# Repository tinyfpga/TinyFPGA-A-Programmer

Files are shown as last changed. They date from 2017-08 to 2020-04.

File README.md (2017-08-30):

# TinyFPGA Programmer
The TinyFPGA Programmer is a very simple USB-JTAG bridge designed to 
program bitstreams onto TinyFPGA A1 and A2 boards.  

## Serial Protocol
The programmer firmware appears as a generic USB serial port when you connect it
to a computer.  Control of the GPIO pins on the programmer is through this simple
serial interface.  

### Command Format
Commands are encoded as 8-bit bytes with a command type field and data payload.
The payload is typically a 6-bit bitmap representing the GPIO pins of the programmer.

| 7:6 | 5 | 4 | 3 | 2 | 1 | 0 |
|---|---|---|---|---|---|---|
| Command Type |TMS|TCK|TDI|TDO|RC1|RC0|

### Commands

|Opcode | Command |
|---|---|
| 0 | Configure Input/Output |
| 1 | Extended Command (Unused) |
| 2 | Set Outputs |
| 3 | Set Outputs and Sample Inputs |

#### Configure Input/Output
For each of the GPIO pins, set the direction of the pin.  
* 1: Set GPIO pin n to INPUT
* 0: Set GPIO pin n to OUTPUT

#### Extended Command
Reserved for future command expansion.

#### Set Outputs
Set each of the output pins to the given values.

#### Set Outputs and Sample Inputs
Set each of the output pins to the given values and return a byte representing
the current values of the input pins.  

### General Usage
For serial interfaces like JTAG this protocol divides the maximum possible bandwidth
by 8 from the USB to JTAG interface.  This means we might get 0.5MHz JTAG programming speed.
That speed is actually fast enough to transfer all the data to the FPGA in a few seconds.  However
the configuration flash on the FPGA actually needs a fair bit of time after erase and write operations
that will slow down the programming operatuon.

What can really slow down programming is the turnaround time for reading back data from the FPGA.  
For the most part data is going in one direction from the host computer to the programmer to the FPGA.  
For these cases we can  use the `Set Outputs` command and not wait for any data to return.  However 
there are times when we may  need to poll a status bit to see if the FPGA has finished an erase or 
write operation.  In this cases we will want to also sample the inputs and check the status.  These 
should not be timing sensitive because the FPGA is already busy.

Verifying the configuration data on the other hand could take a long time if not done carefully.  The
application talking to the programmer should make sure to write as many commands as it can before attempting
to read back the data from the serial interface.  Rather than paying a penalty for the turnaround time on
every read bit, we pay for it after reading dozens of bytes.  This should allow read-back of the configuration
data to be relatively quick and painless.

## Status
The project is currently in progress.  Initial schematic and PCBs have
been designed along with firmware for the USB microcontroller.  The PCBs
have been received from OSH Park and programmed with the firwmware.

The biggest task left is still developing the Python libraries for interfacing 
with the firmware and driving the JTAG interface and is currently in progress.

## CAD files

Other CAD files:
firmware/dist/default/production/firmware.production.obj

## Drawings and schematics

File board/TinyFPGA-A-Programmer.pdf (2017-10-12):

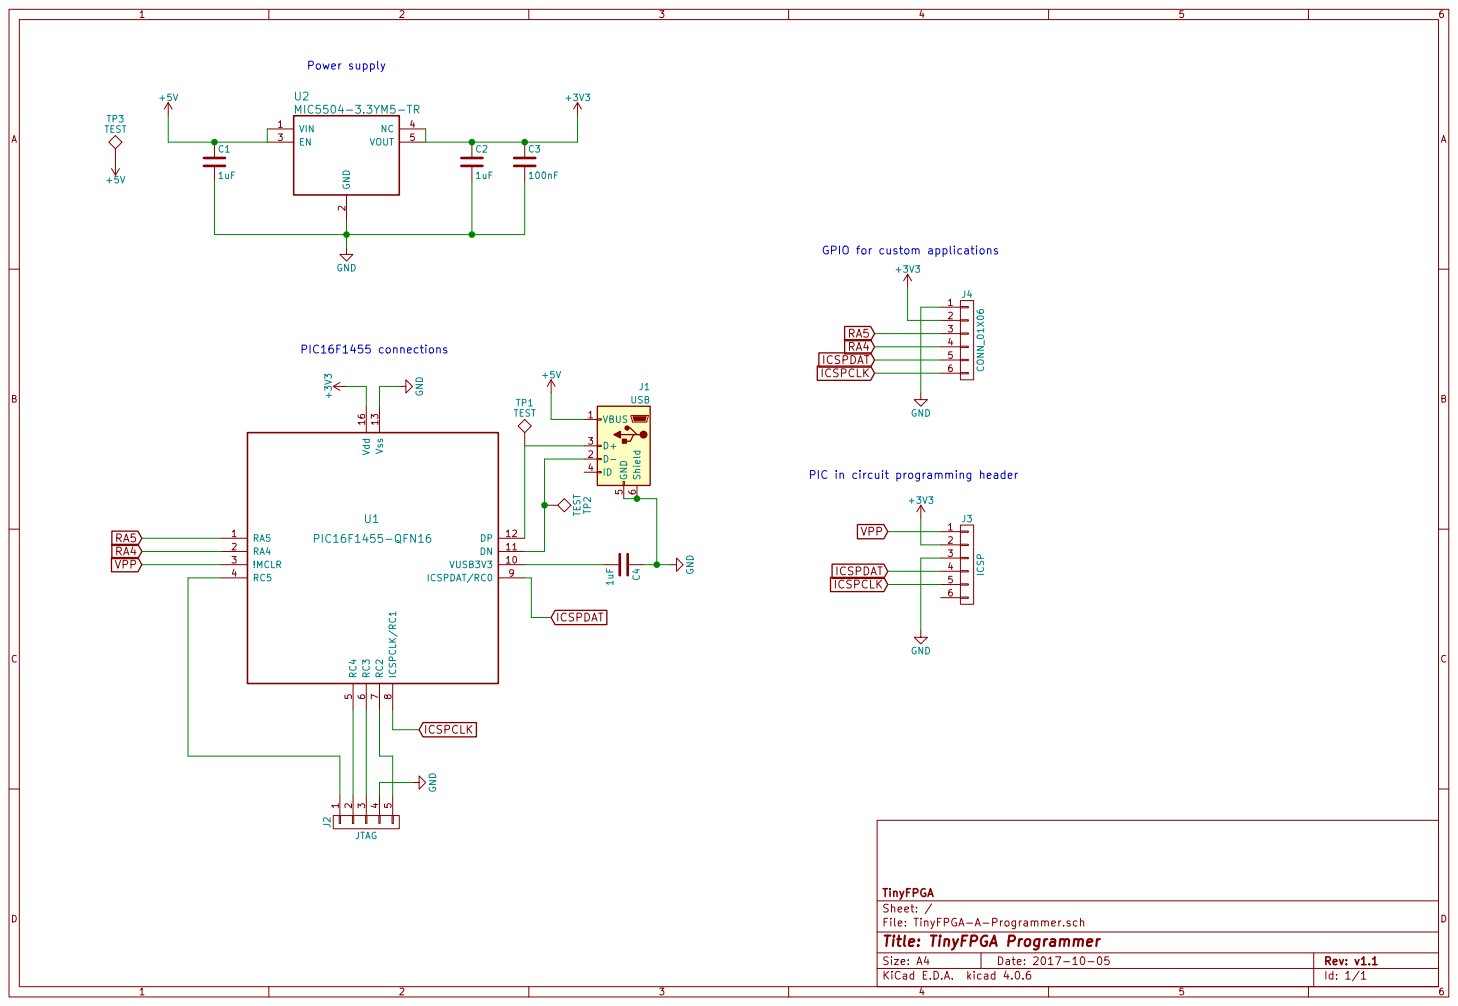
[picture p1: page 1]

PIC in circuit programming header

File: TinyFPGA-A-Programmer.sch Sheet: / TinyFPGA

Id: 1/1 Title: TinyFPGA Programmer

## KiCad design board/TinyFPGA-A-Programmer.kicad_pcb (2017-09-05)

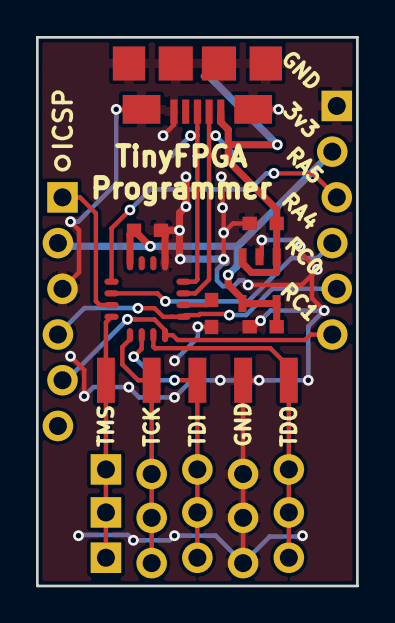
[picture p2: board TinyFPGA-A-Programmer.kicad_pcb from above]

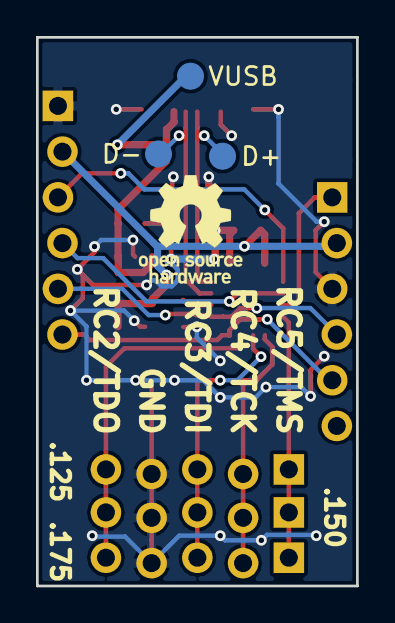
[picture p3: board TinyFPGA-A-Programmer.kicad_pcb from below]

Board: 2 copper layers, 17.8 x 30.5 mm, 16 parts (3 on the bottom side), 15 nets.

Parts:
C1, C2, C4: 1uF; C_0603
C3: 100nF; C_0603
D+: TEST; Measurement_Point_Round-SMD-Pad_Small
D-: TEST; Measurement_Point_Round-SMD-Pad_Small
J1: USB; FCI-Micro-USB
J2: JTAG; Pin_Header_Straight_1x05_Pitch2.54mm_SMD
J2#2, J2#3, J2#4: JTAG; Pin_Header_Straight_1x05_Pitch2.54mm
J3: ICSP; Pin_Header_Straight_1x06_Pitch2.54mm
J4: CONN_01X06; Pin_Header_Straight_1x06_Pitch2.54mm
U1: PIC16F1455-QFN16; QFN-16-1EP_4x4mm_Pitch0.65mm
U2: MIC5504-3.3YM5-TR; SOT23
VUSB: TEST; Measurement_Point_Round-SMD-Pad_Small

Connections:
+3V3: C2.1, C3.1, J3.2, J4.2, U1.16, U2.4, U2.5
+5V: C1.1, J1.1, U2.1, U2.3, VUSB.1
GND: C1.2, C2.2, C3.2, C4.1, J1.5, J1.6, J2.4, J2#2.4, J2#3.4, J2#4.4, J3.3, J4.1, U1.13, U2.2
ICSPCLK: J3.5, J4.6, U1.8
ICSPDAT: J3.4, J4.5, U1.9
unnamed: C4.2, U1.10
unnamed: D-.1, J1.2, U1.11
unnamed: D+.1, J1.3, U1.12
unnamed: J2.1, J2#2.1, J2#3.1, J2#4.1, U1.4
unnamed: J2.2, J2#2.2, J2#3.2, J2#4.2, U1.5
unnamed: J2.3, J2#2.3, J2#3.3, J2#4.3, U1.6
unnamed: J2.5, J2#2.5, J2#3.5, J2#4.5, U1.7
RA4: J4.4, U1.2
RA5: J4.3, U1.1
VPP: J3.1, U1.3

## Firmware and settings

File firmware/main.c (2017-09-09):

/*
 * USB GPIO FW for a PIC16F1455.
 * 2017 Luke Valenty (lvalenty@gmail.com) 
 * 
 * This FW implements a very simple USB GPIO device using a PIC16F1455
 * microcontroller.  It enables control of the lower 6 PORTC GPIO pins 
 * for both input and output.  Input/output settings are configurable at
 * runtime.
 * 
 * The primary purpose of this FW is to allow the development of a cheap
 * JTAG programmer board for the TinyFPGA A-Series boards.  However, because
 * of it's flexibility it may be used for other tasks as well.
 */

#include "stdint.h"

#define MAX_PKT_SIZE 64

volatile uint8_t usb_tx_buf_0[MAX_PKT_SIZE] __at(0x0A0);
volatile uint8_t usb_rx_buf_0[MAX_PKT_SIZE] __at(0x120);
volatile uint8_t usb_tx_buf_1[MAX_PKT_SIZE] __at(0x1A0);
volatile uint8_t usb_rx_buf_1[MAX_PKT_SIZE] __at(0x220);

uint8_t* usb_tx_buf = usb_tx_buf_0;
uint8_t* usb_rx_buf = usb_rx_buf_0;

uint8_t* usb_tx_buf_array[2] = {usb_tx_buf_0, usb_tx_buf_1};
uint8_t* usb_rx_buf_array[2] = {usb_rx_buf_0, usb_rx_buf_1};

#include "mcc_generated_files/mcc.h"
#include "pt.h"
#include "stdio.h"

static uint8_t usb_rx_bytes_avail = 0;
static uint8_t usb_rx_ptr = 0;
static uint8_t usb_tx_ptr = 0;

struct sie_config_t {
    uint8_t config_byte;
    uint8_t input_mask;
    uint8_t do0p0;
    uint8_t do0p1;
    uint8_t do1p0;
    uint8_t do1p1;
    uint8_t last_phase_overlay;
    uint8_t dummy;
};

static struct sie_config_t sie_configs[8];

#define GET_BYTE(pt, dst)\
    PT_WAIT_UNTIL(pt, usb_rx_ptr < usb_rx_bytes_avail);\
    dst = usb_rx_buf[usb_rx_ptr];\
    usb_rx_ptr += 1;

#define SEND_BYTE(pt, src)\
    PT_WAIT_UNTIL(pt, USBUSARTIsTxTrfReady() && (usb_tx_ptr < MAX_PKT_SIZE));\
    usb_tx_buf[usb_tx_ptr] = src;\
    usb_tx_ptr += 1;

void inline gpio_init() {
    TRISC = 0b111111;
}


////////////////////////////////////////////////////////////////////////////////
////////////////////////////////////////////////////////////////////////////////
///
/// Process GPIO and SIE commands from host.
///
////////////////////////////////////////////////////////////////////////////////
////////////////////////////////////////////////////////////////////////////////

/**
 * FIXME: this is outdated, please update with latest command definitions
 * Command Structure
 * -----------------
 * bit 7-6: Command Type
 * bit 5-0: Command Data
 * 
 * Command Types
 * -------------
 * 0: CFG - Configure Input/Output
 *     Command data represents GPIO pins 5-0
 *     1: set GPIO pin n to INPUT
 *     0: set GPIO pin n to OUTPUT
 * 
 * 1: EXT - Extended Command
 *     Currently unused
 * 
 * 2: SET - Set output pins without sampling inputs
 *     1: set output GPIO pin n to 1
 *     0: set output GPIO pin n to 0
 *     For INPUT pins there is no change
 * 
 * 3: SETGET - Set output pins and return current value of input pins
 *     Same encoding as SET but a bitmap representing current state of input
 *     pins is returned.
 */
PT_THREAD(inline cmd_task(struct pt* pt)) {
    static uint8_t gpio_dir = 0b111111;
    
    static uint8_t cmd;
    static uint8_t op0;
    static uint8_t sie;
    static uint8_t num_bits;
    static uint8_t num_bytes;
    static uint8_t input_mask;
    static uint8_t do0p0;
    static uint8_t do0p1;
    static uint8_t do1p0;
    static uint8_t do1p1;
    static uint8_t inout_cfg;
    static uint8_t i;
    
    static uint8_t loop_start = 3; // loop is always contained in a single packet
    static uint16_t loop_count;
    static uint8_t loop_is_active = 0;
    
    
    static uint8_t actual_data;
    static uint8_t expected_data;
    static uint8_t mask;
    
    static uint8_t byte_to_send;
    
    
    static uint8_t compare_data_matches = 1;
    static uint8_t data;
    
    static const uint8_t STATUS_SUCCESS = 0;
    static const uint8_t STATUS_FAIL = 1;
    static uint8_t status = 0; 
    static uint8_t status_sent = 0;
    
    PT_BEGIN(pt);
    
    while (1) {
        PT_YIELD(pt);
        GET_BYTE(pt, cmd);
        
        
    
        //printf("CMD: %02x", cmd);
        
        op0 = cmd & 0xc0;
        
        if (op0 == 0x40) {
            // SET CMD
            LATC = cmd & ~gpio_dir;
            
        } else if (op0 == 0x80) {
            // SET_GET CMD
            byte_to_send = PORTC & gpio_dir;
            LATC = cmd & ~gpio_dir;
            SEND_BYTE(pt, byte_to_send);
            
        } else {
            uint8_t op1 = cmd & 0xF8;
            
            if (op1 == 0x18) {
                // SHIFT CMD
                sie = cmd & 0x7;

                GET_BYTE(pt, num_bits);
                GET_BYTE(pt, num_bytes);
                
                do0p0 = sie_configs[sie].do0p0;
                do0p1 = sie_configs[sie].do0p1;
                inout_cfg = sie_configs[sie].config_byte & 0xf;
                
                
                if (inout_cfg == 0x0C) { // DATA COMPARE ONLY
                    compare_data_matches = 1;
                    
                    input_mask = sie_configs[sie].input_mask;
                
                    for (i = 0; i < num_bytes; i += 1) {
                        actual_data = 0;
                        
                        LATC = do0p0;
                        LATC = do0p1;
                        if (PORTC & input_mask) actual_data = actual_data | 0x01;
                        
                        LATC = do0p0;
                        LATC = do0p1;
                        if (PORTC & input_mask) actual_data = actual_data | 0x02;
                        
                        LATC = do0p0;
                        LATC = do0p1;
                        if (PORTC & input_mask) actual_data = actual_data | 0x04;
                        
                        LATC = do0p0;
                        LATC = do0p1;
                        if (PORTC & input_mask) actual_data = actual_data | 0x08;
                        
                        LATC = do0p0;
                        LATC = do0p1;
                        if (PORTC & input_mask) actual_data = actual_data | 0x10;
                        
                        LATC = do0p0;
                        LATC = do0p1;
                        if (PORTC & input_mask) actual_data = actual_data | 0x20;
                        
                        LATC = do0p0;
                        LATC = do0p1;
                        if (PORTC & input_mask) actual_data = actual_data | 0x40;
                        
                        LATC = do0p0;
                        LATC = do0p1;
                        if (PORTC & input_mask) actual_data = actual_data | 0x80;
                 
                        
                        GET_BYTE(pt, expected_data);
                        GET_BYTE(pt, mask);
                        
                        if ((expected_data & mask) != (actual_data & mask)) {
                            compare_data_matches = 0;
                        }
                    }

                    actual_data = 0;
                    uint8_t bit_to_set = 1;

                    for (i = 0; i < num_bits - 1; i += 1) {
                        LATC = do0p0;
                        LATC = do0p1;
                        if (PORTC & input_mask) actual_data = actual_data | bit_to_set;

                        bit_to_set = bit_to_set << 1;
                    }
                
                    uint8_t last_phase_overlay = sie_configs[sie].last_phase_overlay;
                            
                    LATC = do0p0 | last_phase_overlay;
                    LATC = do0p1 | last_phase_overlay;
                    if (PORTC & input_mask) actual_data = actual_data | bit_to_set;
                    
                    
                    GET_BYTE(pt, expected_data);
                    GET_BYTE(pt, mask);

                    if ((expected_data & mask) != (actual_data & mask)) {
                        compare_data_matches = 0;
                    }
                    
                    if (loop_is_active) {
                        if (compare_data_matches) {
                            loop_is_active = 0;
                        }
                    } else {
                        if (!compare_data_matches) {
                            status = STATUS_FAIL;
                            
                            if (!status_sent) {
                                SEND_BYTE(pt, STATUS_FAIL);
                                status_sent = 1;
                            }
                        }
                    }
                    
                    
                    
                } else if (inout_cfg == 4) { // SHIFT DATA IN ONLY
                    input_mask = sie_configs[sie].input_mask;
                
                    for (i = 0; i < num_bytes; i += 1) {
                        data = 0;
                        
                        LATC = do0p0;
                        LATC = do0p1;
                        if (PORTC & input_mask) data = data | 0x01;
                        
                        LATC = do0p0;
                        LATC = do0p1;
                        if (PORTC & input_mask) data = data | 0x02;
                        
                        LATC = do0p0;
                        LATC = do0p1;
                        if (PORTC & input_mask) data = data | 0x04;
                        
                        LATC = do0p0;
                        LATC = do0p1;
                        if (PORTC & input_mask) data = data | 0x08;
                        
                        LATC = do0p0;
                        LATC = do0p1;
                        if (PORTC & input_mask) data = data | 0x10;
                        
                        LATC = do0p0;
                        LATC = do0p1;
                        if (PORTC & input_mask) data = data | 0x20;
                        
                        LATC = do0p0;
                        LATC = do0p1;
                        if (PORTC & input_mask) data = data | 0x40;
                        
                        LATC = do0p0;
                        LATC = do0p1;
                        if (PORTC & input_mask) data = data | 0x80;
                 
                        SEND_BYTE(pt, data);
                    }

                    data = 0;
                    uint8_t bit_to_set = 1;

                    for (i = 0; i < num_bits - 1; i += 1) {
                        LATC = do0p0;
                        LATC = do0p1;
                        if (PORTC & input_mask) data = data | bit_to_set;

                        bit_to_set = bit_to_set << 1;
                    }
                
                    uint8_t last_phase_overlay = sie_configs[sie].last_phase_overlay;
                            
                    LATC = do0p0 | last_phase_overlay;
                    LATC = do0p1 | last_phase_overlay;
                    if (PORTC & input_mask) data = data | bit_to_set;
                    
                    SEND_BYTE(pt, data);
                
                } else if (inout_cfg == 1) { // SHIFT DATA OUT ONLY
                    do1p0 = sie_configs[sie].do1p0;
                    do1p1 = sie_configs[sie].do1p1;
                
                    for (i = 0; i < num_bytes; i += 1) {
                        GET_BYTE(pt, uint8_t data);
                        
                        if (data & 0x01) {
                            LATC = do1p0;
                            LATC = do1p1;
                        } else {
                            LATC = do0p0;
                            LATC = do0p1;
                        }
                        
                        if (data & 0x02) {
                            LATC = do1p0;
                            LATC = do1p1;
                        } else {
                            LATC = do0p0;
                            LATC = do0p1;
                        }
                        
                        if (data & 0x04) {
                            LATC = do1p0;
                            LATC = do1p1;
                        } else {
                            LATC = do0p0;
                            LATC = do0p1;
                        }
                        
                        if (data & 0x08) {
                            LATC = do1p0;
                            LATC = do1p1;
                        } else {
                            LATC = do0p0;
                            LATC = do0p1;
                        }
                        
                        if (data & 0x10) {
                            LATC = do1p0;
                            LATC = do1p1;
                        } else {
                            LATC = do0p0;
                            LATC = do0p1;
                        }
                        
                        if (data & 0x20) {
                            LATC = do1p0;
                            LATC = do1p1;
                        } else {
                            LATC = do0p0;
                            LATC = do0p1;
                        }
                        
                        if (data & 0x40) {
                            LATC = do1p0;
                            LATC = do1p1;
                        } else {
                            LATC = do0p0;
                            LATC = do0p1;
                        }
                        
                        if (data & 0x80) {
                            LATC = do1p0;
                            LATC = do1p1;
                        } else {
                            LATC = do0p0;
                            LATC = do0p1;
                        }
                    }

                    GET_BYTE(pt, uint8_t data);

                    for (i = 0; i < num_bits - 1; i += 1) {
                        if (data & 1) {
                            LATC = do1p0;
                            LATC = do1p1;
                        } else {
                            LATC = do0p0;
                            LATC = do0p1;
                        }

                        data = data >> 1;
                    }
                
                    uint8_t last_phase_overlay = sie_configs[sie].last_phase_overlay;
                            
                    if (data & 1) {
                        LATC = do1p0 | last_phase_overlay;
                        LATC = do1p1 | last_phase_overlay;
                    } else {
                        LATC = do0p0 | last_phase_overlay;
                        LATC = do0p1 | last_phase_overlay;
                    }
                    
                } else if (inout_cfg == 0) { // RUN PHASE 0 PATTERN ONLY
                    for (i = 0; i < num_bytes; i += 1) {
                        LATC = do0p0;
                        LATC = do0p1;
                        LATC = do0p0;
                        LATC = do0p1;
                        LATC = do0p0;
                        LATC = do0p1;
                        LATC = do0p0;
                        LATC = do0p1;
                        LATC = do0p0;
                        LATC = do0p1;
                        LATC = do0p0;
                        LATC = do0p1;
                        LATC = do0p0;
                        LATC = do0p1;
                        LATC = do0p0;
                        LATC = do0p1;
                    }

                    for (i = 0; i < num_bits; i += 1) {
                        LATC = do0p0;
                        LATC = do0p1;
                    }
                }
                
            } else if (cmd == 0x10) {
                // LOOP CMD
                GET_BYTE(pt, uint8_t tmp);
                loop_count = tmp;
                
                GET_BYTE(pt, tmp);
                loop_count |= ((uint16_t) tmp) << 8;
                
                loop_is_active = 1;
                
            } else if (cmd == 0x11) {
                // END_LOOP CMD
                loop_count -= 1;
                
                if (loop_count > 0) {
                    if (loop_is_active) {
                        // loop is not complete, continue
                        usb_rx_ptr = loop_start;
                    } else {
                        // loop is complete, exit loop
                    }
                    
                } else {
                    // loop counter has expired, check if loop is active
                    if (loop_is_active) {
                        // we should have matched before now, send error
                        status = STATUS_FAIL;
                        status_sent = 1;
                        SEND_BYTE(pt, STATUS_FAIL);
                    }
                    
                    loop_is_active = 0;
                }
                
                
                
            } else if (op1 == 0x08) {
                // CONFIG_SIE CMD
                sie = cmd & 0x7;
                
                GET_BYTE(pt, sie_configs[sie].config_byte);
                GET_BYTE(pt, sie_configs[sie].input_mask);
                GET_BYTE(pt, sie_configs[sie].do0p0);
                GET_BYTE(pt, sie_configs[sie].do0p1);
                GET_BYTE(pt, sie_configs[sie].do1p0);
                GET_BYTE(pt, sie_configs[sie].do1p1);
                GET_BYTE(pt, sie_configs[sie].last_phase_overlay);
                
            } else if (cmd == 0x20) {
                // CLEAR STATUS CMD
                status = STATUS_SUCCESS;
                status_sent = 0;
                
            } else if (cmd == 0x21) {
                // GET STATUS CMD
                SEND_BYTE(pt, status);
                status_sent = 1;
                
            } else {
                // CONFIG_IO CMD
                GET_BYTE(pt, cmd);
                gpio_dir = cmd & 0x3f;
                TRISC = gpio_dir;
            }
        }
        
                
    } // while
    
    PT_END(pt); 
}


////////////////////////////////////////////////////////////////////////////////
////////////////////////////////////////////////////////////////////////////////
///
/// Manage RX buffer
///
////////////////////////////////////////////////////////////////////////////////
////////////////////////////////////////////////////////////////////////////////

////////////////////////////////////////
// RX buffer ping-pong management variables
static BDT_ENTRY* usb_rx_pp_handle[2] = {(BDT_ENTRY*) 0x2020, (BDT_ENTRY*) 0x2024}; // EP2_OUT_EVEN, EP2_OUT_ODD
static uint8_t usb_rx_pp_size = 0;
static uint8_t usb_rx_pp_put_ptr;
static uint8_t usb_rx_pp_get_ptr;
static uint8_t bytes_recieved;
static BDT_ENTRY* current_rx_handle = 0x2020;

/**
 * Continuously attempts to fill as many of the two RX buffers as
 * possible.  It uses the usb_rx_pp_size variable to determine how many of the
 * buffers it is allowed to fill.
 */
PT_THREAD(inline cmd_rx_buf_put_task(struct pt* pt)) {
    PT_BEGIN(pt);
    
    usb_rx_pp_put_ptr = 0;
    
    while (1) {
        // wait until there is a data buffer available to fill
        PT_WAIT_UNTIL(pt, usb_rx_pp_size < 2);
        
        current_rx_handle = usb_rx_pp_handle[usb_rx_pp_put_ptr];
        
        do {
            bytes_recieved = 0;
            
            // setup rx buffer descriptor and give it to the USB controller
            current_rx_handle->ADR = ConvertToPhysicalAddress(usb_rx_buf_array[usb_rx_pp_put_ptr]);
            current_rx_handle->CNT = MAX_PKT_SIZE;
            current_rx_handle->STAT.Val &= _DTSMASK;
            current_rx_handle->STAT.Val |= _DTSEN;
            current_rx_handle->STAT.Val |= _USIE;

            PT_WAIT_UNTIL(pt, current_rx_handle->STAT.UOWN == 0);
            bytes_recieved = current_rx_handle->CNT;
                    
            PT_YIELD(pt);
        } while (bytes_recieved == 0);
        
        usb_rx_pp_size += 1;
        usb_rx_pp_put_ptr ^= 1;
    }
    
    PT_END(pt);
}

/**
 * Manages updating the usb_rx_ptr and usb_rx_buf variables when new data is
 * available to process.  Updates usb_rx_pp_size to let the put_task know more
 * space is available to put data from USB.
 */
PT_THREAD(inline cmd_rx_buf_get_task(struct pt* pt)) {
    PT_BEGIN(pt);
    
    usb_rx_pp_get_ptr = 0;
    
    while (1) {
        // wait until there is a data buffer that's been filled
        PT_WAIT_UNTIL(pt, usb_rx_pp_size > 0);
        
        // setup buffer for GPIO engine to consume its contents
        usb_rx_buf = usb_rx_buf_array[usb_rx_pp_get_ptr];
        usb_rx_ptr = 0;
        usb_rx_bytes_avail = usb_rx_pp_handle[usb_rx_pp_get_ptr]->CNT;
        
        // wait until the data has been drained from this buffer
        PT_WAIT_UNTIL(pt, usb_rx_ptr >= usb_rx_bytes_avail);
        
        usb_rx_pp_size -= 1;
        usb_rx_pp_get_ptr ^= 1;
    }
    
    PT_END(pt);
}



////////////////////////////////////////////////////////////////////////////////
////////////////////////////////////////////////////////////////////////////////
///
/// Manage TX buffer
///
////////////////////////////////////////////////////////////////////////////////
////////////////////////////////////////////////////////////////////////////////
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
void main(void) {
    struct pt cmd_pt;
    PT_INIT(&cmd_pt);
    
    struct pt tx_pt;
    PT_INIT(&tx_pt);
    
    struct pt rx_put_pt;
    PT_INIT(&rx_put_pt);
    
    struct pt rx_get_pt;
    PT_INIT(&rx_get_pt);
    
    SYSTEM_Initialize();
    USBDeviceInit();
    gpio_init();
    
    while (1) {
        USBDeviceTasks();
        
        if (
            (USBGetDeviceState() >= CONFIGURED_STATE) &&
            (USBIsDeviceSuspended() == false)
        ) {
            cmd_rx_buf_put_task(&rx_put_pt);
            cmd_rx_buf_get_task(&rx_get_pt);
            cmd_tx_buffer_task(&tx_pt);
            cmd_task(&cmd_pt);
        }
    }
}

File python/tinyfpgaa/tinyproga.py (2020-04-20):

import sys
import traceback
import argparse
import serial
from serial.tools.list_ports import comports
import tinyfpgaa

def main():
    parser = argparse.ArgumentParser()
    parser.add_argument("-q", action="store_true", help="Silent mode.")
    parser.add_argument("-p", type=str, help="Manually specify serial device.")
    parser.add_argument("-b", action="store_true", help="Input is bitstream file.")
    parser.add_argument("jed", type=str, help="JEDEC or bitstream file to program.")
    args = parser.parse_args()

    if not args.p:
        for port in comports():
            if "1209:2101" in port[2]:
                a_port = port[0]
                break
        else:
            print("TinyFPGA A not detected! Is it plugged in?")
            sys.exit(1)
    else:
        a_port = args.p

    with serial.Serial(a_port, 12000000, timeout=10, writeTimeout=5) as ser:
        async_serial = tinyfpgaa.SyncSerial(ser)
        pins = tinyfpgaa.JtagTinyFpgaProgrammer(async_serial)
        jtag = tinyfpgaa.Jtag(pins)
        programmer = tinyfpgaa.JtagCustomProgrammer(jtag)

        if not args.q:
            if args.b:
                print("Parsing bitstream file...")
            else:
                print("Parsing JEDEC file...")

        if args.b:
            input_file = tinyfpgaa.BitstreamFile(open(args.jed, 'rb'))
        else:
            input_file = tinyfpgaa.JedecFile(open(args.jed, 'r'))

        try:
            if not args.q:
                print("Programming TinyFPGA A on {}...".format(a_port))
            programmer.program(input_file)
        except:
            print("Programming Failed!")
            traceback.print_exc()
            sys.exit(2)

    print("Programming finished without error.")

if __name__ == "__main__":
    main()

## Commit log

2017-08-03 add pic firmware
    [firmware.production.obj]
2017-08-05 added programmer schematic and pcb layout
    [TinyFPGA-A-Programmer.kicad_pcb, TinyFPGA-A-Programmer.sch]
2017-08-30 updated firmware to read from TDO
    [firmware.production.obj]
2017-09-01 updated CPU clock multiplier for firmware
    [firmware.production.obj]
2017-09-04 big changes to drastically speed up flash program times
    [firmware.production.obj]
2017-09-05 updated schematic and PCB
    [TinyFPGA-A-Programmer.kicad_pcb, TinyFPGA-A-Programmer.sch]
2017-09-09 firmware ready for production
    [firmware.production.obj]
2017-09-15 fix bug related to MacOS
    [tinyfpgaa.py]
2017-09-15 Update tinyfpgaa.py
    workaround for bug in firmware related to MacOS virtual serial port driver and zero length data packets.
    [tinyfpgaa.py]
2017-09-21 updates to improve stability on MacOS
    [tinyfpgaa.py]
2017-10-02 fixed bug with programming EBR initialization data
    [tinyfpgaa.py]
2017-10-07 production firmware, added schematic pdf
    [TinyFPGA-A-Programmer.sch, firmware.production.obj]
2017-10-12 fixed introduced bug where jed fiels without ebr now fail
    [tinyfpgaa.py]
2021-02-03 fix for py39 https://bugs.python.org/issue38916
    [tinyfpgaa.py]
2022-05-30 Support editable installs correctly.
    [tinyfpgaa.py, tinyproga.py]
